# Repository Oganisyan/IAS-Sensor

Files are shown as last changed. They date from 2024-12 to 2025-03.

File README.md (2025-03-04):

# IAS-Sensor for Paraglider
IAS Sensor for Paraglider





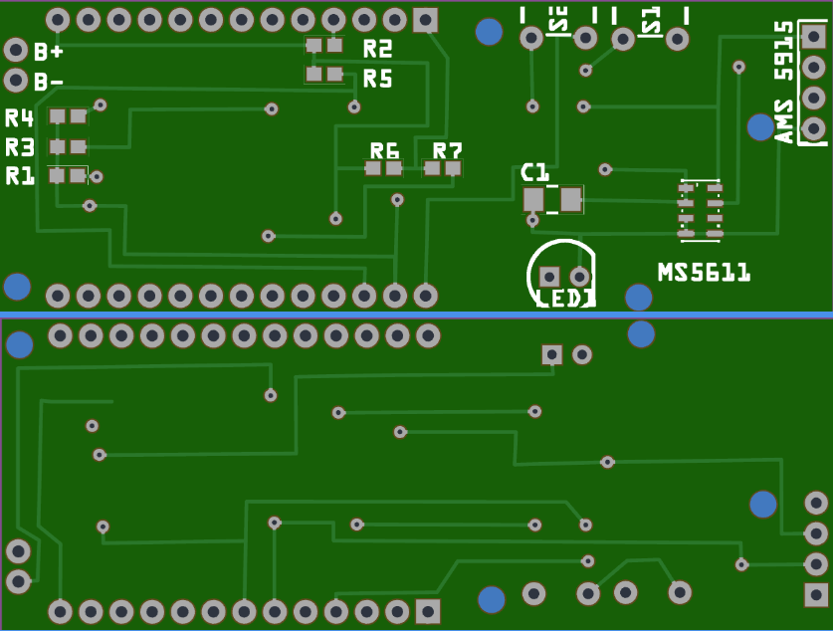
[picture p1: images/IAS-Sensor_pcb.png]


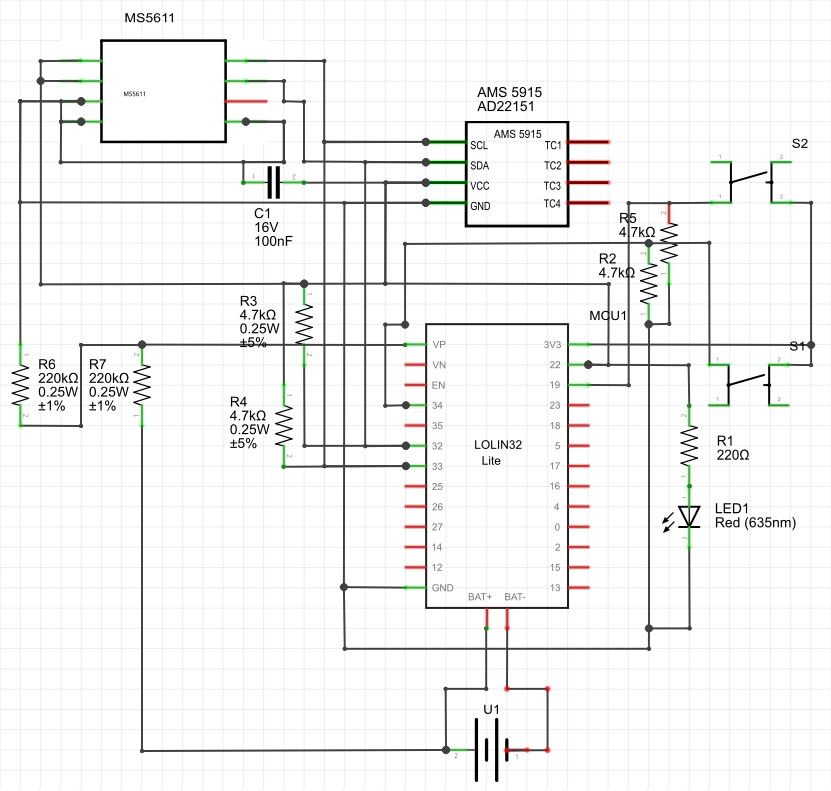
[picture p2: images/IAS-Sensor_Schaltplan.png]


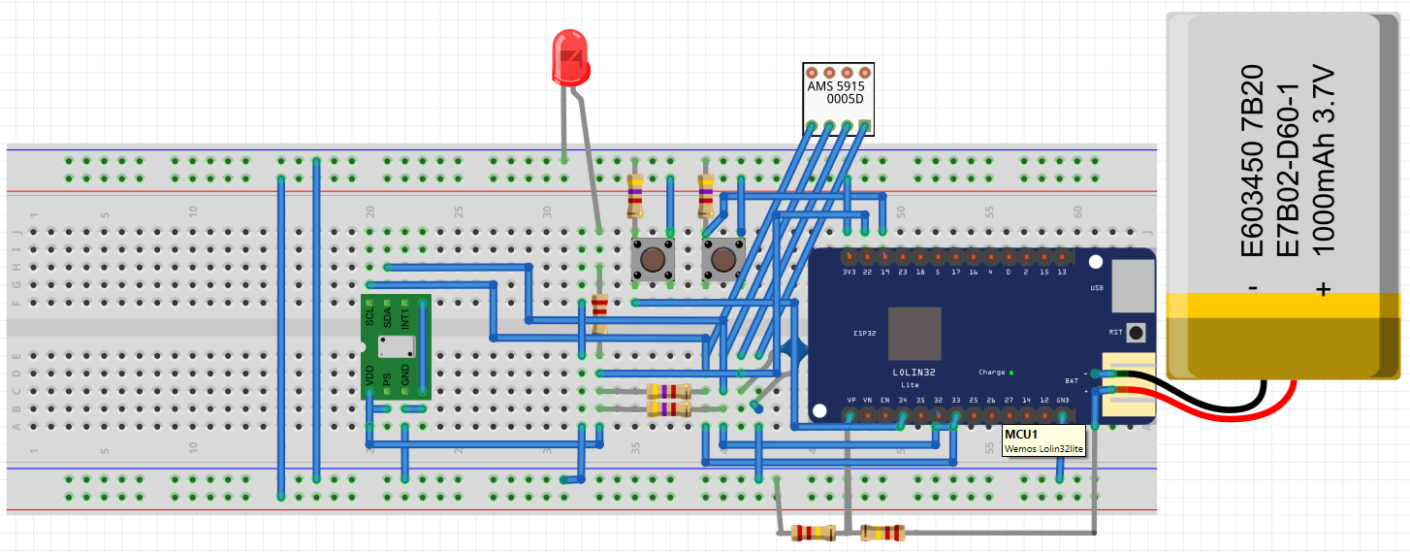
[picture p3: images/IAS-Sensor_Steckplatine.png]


# Mounting on the paraglider
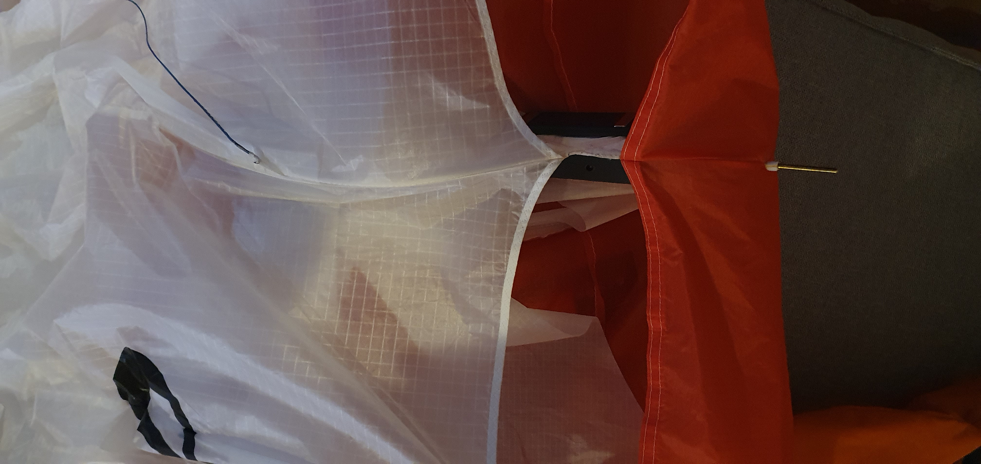
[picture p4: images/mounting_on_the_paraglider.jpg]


# Source Code

[Code](./src/IAS-Sensor/)

# Source for 3D Printing & PCB
## Case
[STL File](./CAD/IAS-SensorV3.stl)

[Tinkercad Repository](https://www.tinkercad.com/things/6USzTzKrwmQ-IAS-SensorV3)
## PCB

[PCB Fritzing File](./board/IAS-Sensor3.fzz)

[PCB Fabricate](https://aisler.net/p/TXLLIEFP)

Amazingly, SeeYou works just as well with an external sensor as the Bräuniger Compeo+. I read barometric data about 12 times per second to smooth it, but I only send it twice per second.
Here’s a video: Unfortunately, the Omni screen is too bright, but the phone and the Compeo+ can be compared well. I also find the acoustics quite good.

https://youtu.be/q-oeLMd8ZC4

Let me know if you need further adjustments! 

# Components

| Name | Amount | Price(~) | Source |
| --- | ---| --- | --- |
| SMD Tate | 2  | 0,42 € |  www.reichelt.de |
| LED | 1  | 0,09 € |  www.reichelt.de |
| R 220 Ω | 1  | 0,02 € |  www.reichelt.de |
| R 4,7 kΩ | 4  | 0,02 € |  www.reichelt.de |
| R 220 kΩ | 2  | 0,02 € |  www.reichelt.de |
| C 100 nF | 1  | 0,02 € |  www.reichelt.de |
| Shipping (reichelt) | 1  | 5,95 € |  www.reichelt.de |
| MS5611 | 1  | 8,37 € |  E-Bay |
| AMS 5915 0005D | 1  | 27,50 € |  www.analog-micro.com |
| Lolin32 Lite | 1  | 5,91 € |  E-Bay |
| Lipo 1000mA | 1  | 6,58 € |  E-Bay |
| Pitot with 3 Outputs | 1  | 30,00 € |  or self-build (show build instructons) |
| Case and lid for MS5611 (3D Print) | 1  | 30,00 € |  or self-build (show build instructons) |
| Circuit board (PCB) | 1  | 8,00 € |  https://aisler.net |

## Price approx:	122,00 €

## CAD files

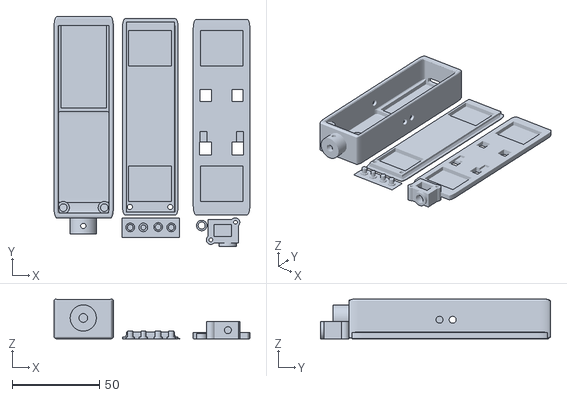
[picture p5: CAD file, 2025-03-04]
CAD/IAS-SensorV3.stl
112.2 x 131.7 x 22.8

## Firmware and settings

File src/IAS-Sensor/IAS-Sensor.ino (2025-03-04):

/*
 Video: https://www.youtube.com/watch?v=oCMOYS71NIU
 Based on Neil Kolban example for IDF: https://github.com/nkolban/esp32-snippets/blob/master/cpp_utils/tests/BLE%20Tests/SampleNotify.cpp
 Ported to Arduino ESP32 by Evandro Copercini

 Create a BLE server that, once we receive a connection, will send periodic notifications.
 The service advertises itself as: 6E400001-B5A3-F393-E0A9-E50E24DCCA9E
 Has a characteristic of: 6E400002-B5A3-F393-E0A9-E50E24DCCA9E - used for receiving data with "WRITE"
 Has a characteristic of: 6E400003-B5A3-F393-E0A9-E50E24DCCA9E - used to send data with  "NOTIFY"

 The design of creating the BLE server is:
 1. Create a BLE Server
 2. Create a BLE Service
 3. Create a BLE Characteristic on the Service
 4. Create a BLE Descriptor on the characteristic
 5. Start the service.
 6. Start advertising.

 In this example rxValue is the data received (only accessible inside that function).
 And txValue is the data to be sent, in this example just a byte incremented every second.
 */
#define CONFIG_LOG_BOOTLOADER_LEVEL_NONE

#include <MyBLEServer.h> 
#include <ASM5915.h>
#include <MS5611.h>
#include <MyUtil.h>
#include <KalmanFilter.h>
#include <PowerManager.h>

#define DEVICE_NAME   "IAS-Sensor"
#define SV_VERSION    1.0
#define HV_VERSION    1.0

#define LPWX0_FOTMATER  "$LXWP0,,%s,%s,%s,,,,,,,,*%02X\r\n"
#define LPWX1_FOTMATER  "$LXWP1,%s,%d,%.2f,%.2f*%02X\r\n"

#define PIN_SDA GPIO_NUM_32
#define PIN_SCL GPIO_NUM_33
#define PIN_POW GPIO_NUM_22  // SENSOR POWER
#define PIN_BTN GPIO_NUM_34  // POW BUTTON
#define PIN_BT2 GPIO_NUM_19  // BUTTON_2 NOT USED
#define PIN_ADC GPIO_NUM_36  // BATARY VOLTAGE /2

#define LOW_BATARY_VOLTAGE	3.5

#if 0
#define DBG(x)  x
#else
#define DBG(x)  
#endif

PowerManager *powerManager = NULL;
MyBLEServer *pServer = NULL;
ASM5915 diffBarometer(Wire);
MS5611 barometer(Wire);
Calculator calculator;
KalmanFilter dKfP;
KalmanFilter dKfT;
KalmanFilter kfP;
KalmanFilter kfT;

String d2s(double d) {
	return isnan(d) ? String() : String(d, 1);
}

const char* getLXWP0(double p, double ias) {
	static char buffer[129];
	double alt;
	double vario;
	calculator.calc(p, alt, vario);
	snprintf(buffer, 128, LPWX0_FOTMATER, d2s(ias).c_str(), d2s(alt).c_str(),
			d2s(vario).c_str(), 0x00);
	snprintf(buffer, 128, LPWX0_FOTMATER, d2s(ias).c_str(), d2s(alt).c_str(),
			d2s(vario).c_str(), calcCheckSum(buffer));
	DBG(Serial.print(buffer));
	return buffer;
}

const char* getLXWP1() {
	static char buffer[129];
	uint32_t serialNumber = 0;
	for (int i = 0; i < 17; i = i + 8) {
		serialNumber |= ((ESP.getEfuseMac() >> (40 - i)) & 0xff) << i;
	}
	snprintf(buffer, 128, LPWX1_FOTMATER, DEVICE_NAME, serialNumber, SV_VERSION,
			HV_VERSION, 0x00);
	snprintf(buffer, 128, LPWX1_FOTMATER, DEVICE_NAME, serialNumber, SV_VERSION,
			HV_VERSION, calcCheckSum(buffer));
	DBG(Serial.print(buffer));
	return buffer;
}

void setup() {
	Serial.begin(115200);
	powerManager = PowerManager::create(PIN_POW, PIN_BTN, PIN_ADC);
	// Create the BLE Device
	pServer = MyBLEServer::create("IAS Sensor", getLXWP1());
	Wire.begin(PIN_SDA, PIN_SCL);
	diffBarometer.begin();
	barometer.begin();
	DBG(Serial.println("Waiting a client connection to notify...");)
}

void loop() {
    double voltage = powerManager->get();
    if(voltage < LOW_BATARY_VOLTAGE) {
    	powerManager->lowPower();
    }
	powerManager->loop();
	for (int i = 0; i < 25; i++) {
		diffBarometer.loop();
		if (diffBarometer.isReady()) {
			dKfP.update(diffBarometer.getPressure());
			dKfT.update(diffBarometer.getTemperature());
		}
		barometer.loop();
		if (barometer.isReady()) {
			kfP.update(barometer.getPressure());
			kfT.update(barometer.getTemperature());
		}
		delay(10);
	}
	if (pServer->isConnected()) {
		pServer->send(getLXWP0(kfP.get(), calcIAS(dKfP.get(), dKfT.get())));
        pServer->sendBatteryLevel(voltage);
	} else {
		DBG(Serial.println("startAdvertising");)
		pServer->startAdvertising();
	}

}

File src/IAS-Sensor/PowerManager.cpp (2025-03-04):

#include <PowerManager.h>

RTC_DATA_ATTR boolean switchOnOff = true;
RTC_DATA_ATTR int lastBtnState = LOW;


const double NaN = std::numeric_limits<double>::quiet_NaN();

PowerManager::PowerManager(gpio_num_t pow, gpio_num_t btn, gpio_num_t adc) :
		pow_(pow), btn_(btn), adc_(adc), vref_(1100) {
	init();
}

PowerManager* PowerManager::create(gpio_num_t pow, gpio_num_t btn, gpio_num_t adc) {
	return new PowerManager(pow, btn, adc);
}

void PowerManager::init() {
	pinMode(adc_, INPUT);
	pinMode(btn_, INPUT);
	loop();
	pinMode(pow_, OUTPUT);
	digitalWrite(pow_, HIGH);
}

void PowerManager::loop() {
	int btnState = digitalRead(btn_);
	if (btnState == LOW && lastBtnState == HIGH) {
		switchOnOff = !switchOnOff;
	}
	lastBtnState = btnState;
	if (!switchOnOff)
		shutdown();
}

void PowerManager::lowPower() {
	pinMode(pow_, OUTPUT);
	for(int i=0; i < 10; i++) {
		digitalWrite(pow_, LOW);
		delay(100);
		digitalWrite(pow_, HIGH);
		delay(100);
	}
	shutdown();
}

void PowerManager::shutdown() {
	//pinMode(pow_, OUTPUT);
	//gpio_hold_en(pow_);
	//digitalWrite(pow_, LOW);
	esp_sleep_enable_ext0_wakeup(btn_, ESP_EXT1_WAKEUP_ANY_HIGH);
	esp_deep_sleep_start();
}

double PowerManager::get() {
	double rv =(analogRead(adc_) * 3.3) / (4095) *2;
	return rv;
}

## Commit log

2024-11-25 first version
    [IAS-Sensor.stl, IAS-Sensor2.fzz]
2024-12-01 Change PowerManager from loop to external wakeup.
2024-12-01 Update Board Infos.
    [IAS-Sensor2.fzz]
2024-12-08 Mounting on the paraglider jpeg
2024-12-22 Add MS5611 Sensor
2024-12-29 Add Arduino header to MyBLEServer.h (just for indexer).
2025-01-24 Add PCB to Project.
    [IAS-Sensor2.fzz]
2025-01-28 update PCB add 100nF capacitor.
    [IAS-Sensor2.fzz]
2025-01-28 update PCB png.
2025-01-30 update IAS-Sensor2.fzz v13
    [IAS-Sensor2.fzz]
2025-02-02 New PCB Design and Price List.
    [IAS-Sensor3.fzz]
2025-02-04 rename IMS 5915 to AMS 5915
    [IAS-Sensor2.fzz, IAS-Sensor3.fzz]
2025-02-08 Update PinOuts.
    [IAS-Sensor3.fzz]
2025-03-04 Add Battery Service
2025-03-04 Add new STL Files
    [IAS-Sensor.stl, IAS-SensorV3.stl]
2025-03-04 add PCB to README.md
    [IAS-Sensor2.fzz]
